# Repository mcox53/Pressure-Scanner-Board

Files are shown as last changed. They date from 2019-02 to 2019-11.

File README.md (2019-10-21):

# Pressure-Scanner-Board

Fab To-Do List:
- ~~Add I2C pull up resistors~~
- ~~Revise SPI pin pads to reflect correct configuration~~
- ~~Edit MCU pins once variant files finalized~~
- ~~Complete board BOM~~
- ~~Create changelog~~
- ~~Create PCB footprints and export netlist~~
- ~~Board layout~~
- ~~Design case~~
- ~~Design review~~
- ~~Finalize and release~~
- ~~Order board + parts~~
- ~~Assemble board~~

Test To-Do List:
- ~~Confirm communication with CAN Controller IC~~
- ~~Incorporate basic changes to variant files to support SPI~~
- ~~Test sending and receiving of CAN messages~~
- ~~Confirm communication with Static Pressure Sensor~~
- ~~Confirm communication with Differential Pressure Sensors~~
- ~~Test code to confirm operation of Differential Pressure Sensors.~~
- Test differential pressure sensors with manometer to verify full range of operation. (CC: Charlie Kniffin)
- Weak solder points of SS_0 and SS_3. Fix at shop with reflow station.
- Draft of application code (reading sensors -> preparing data frames -> sending over CAN)
- Prepare Interface Control Document (ICD) and add to AIM CAN configuration
- Finalize application code

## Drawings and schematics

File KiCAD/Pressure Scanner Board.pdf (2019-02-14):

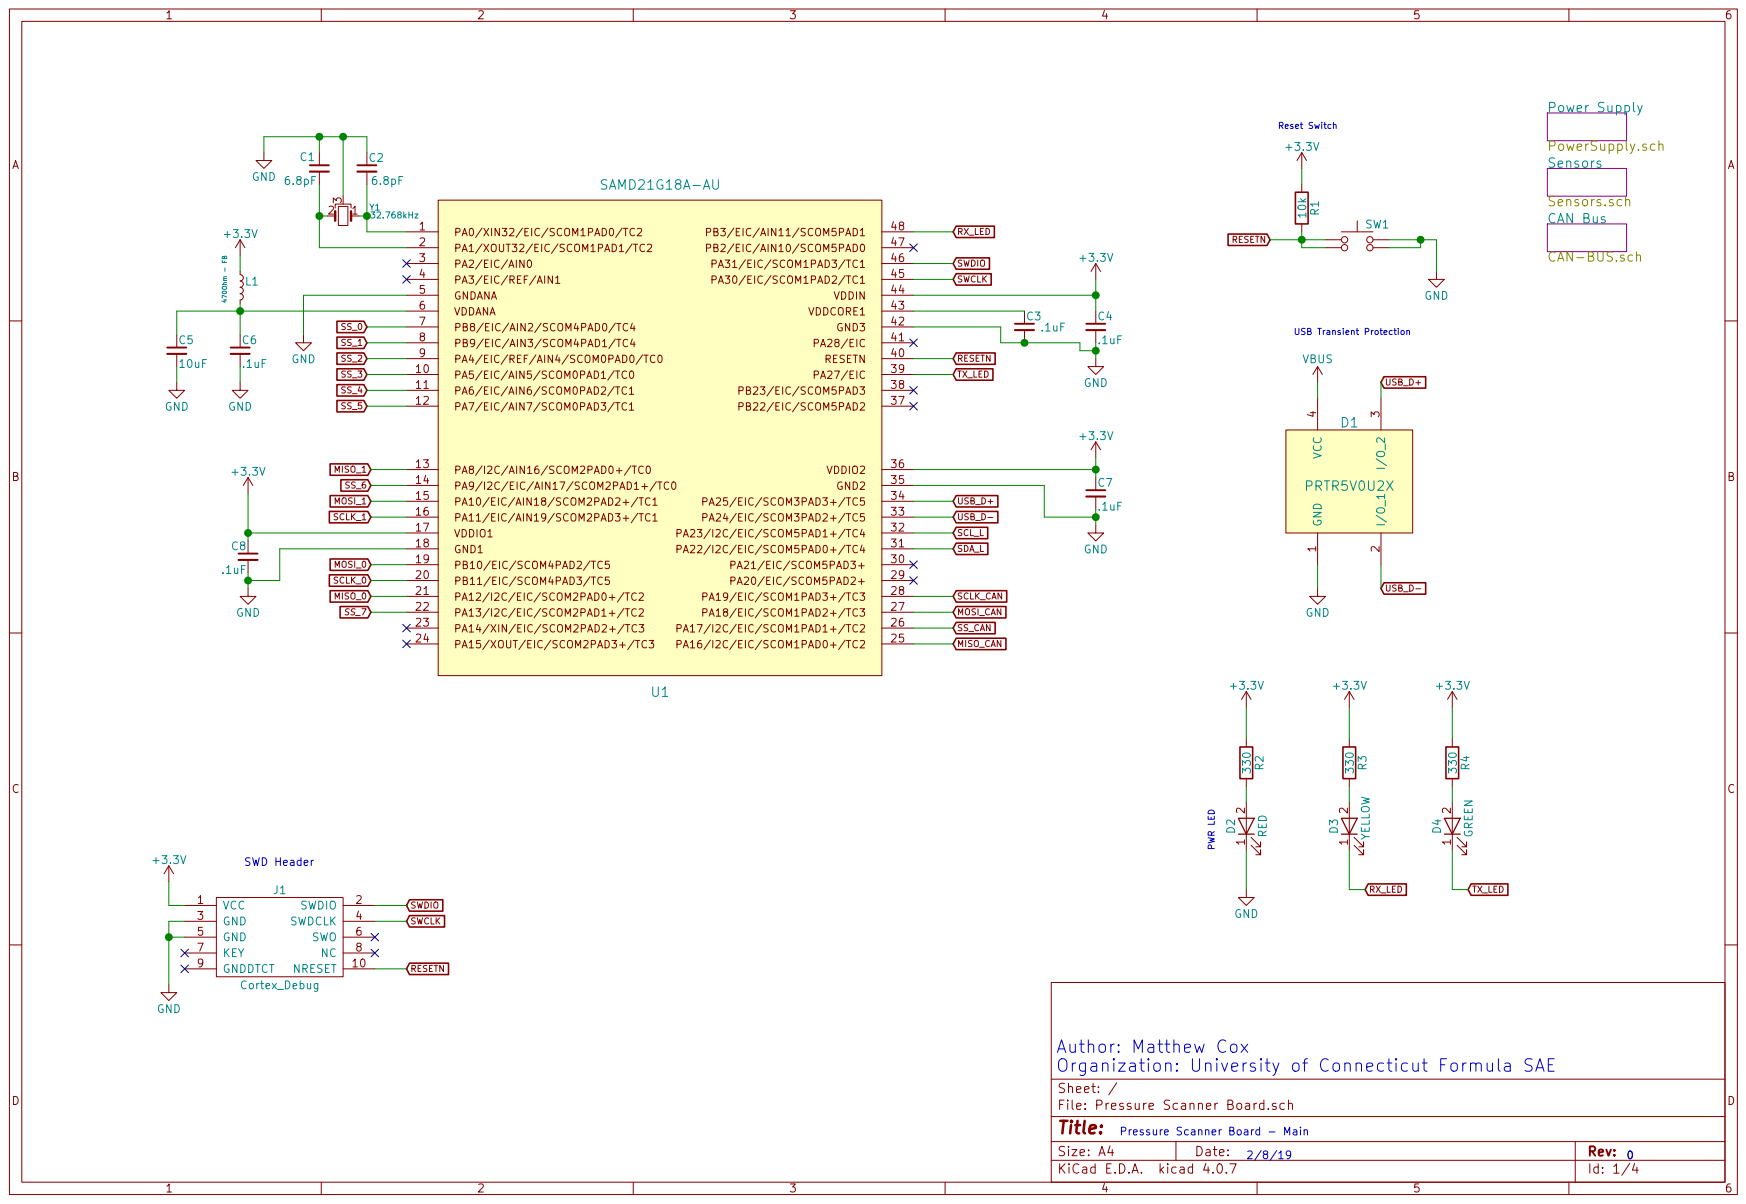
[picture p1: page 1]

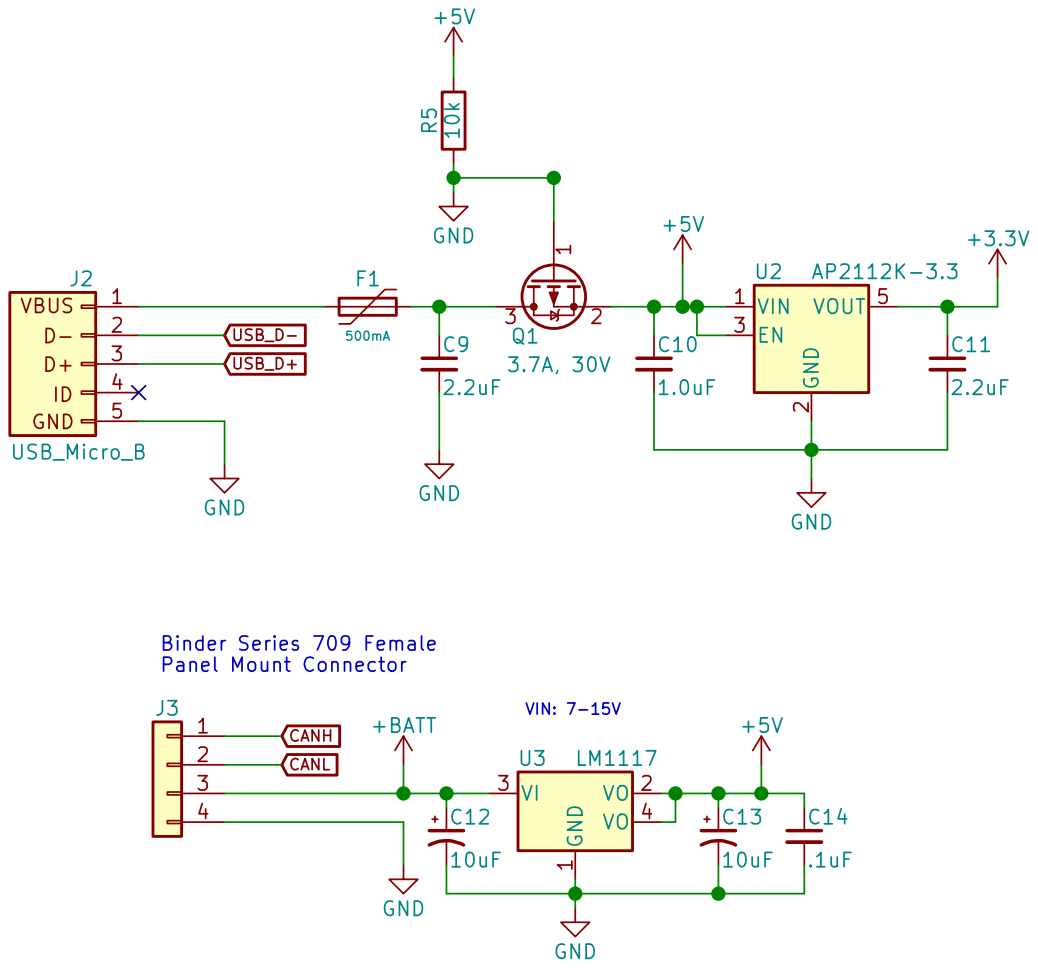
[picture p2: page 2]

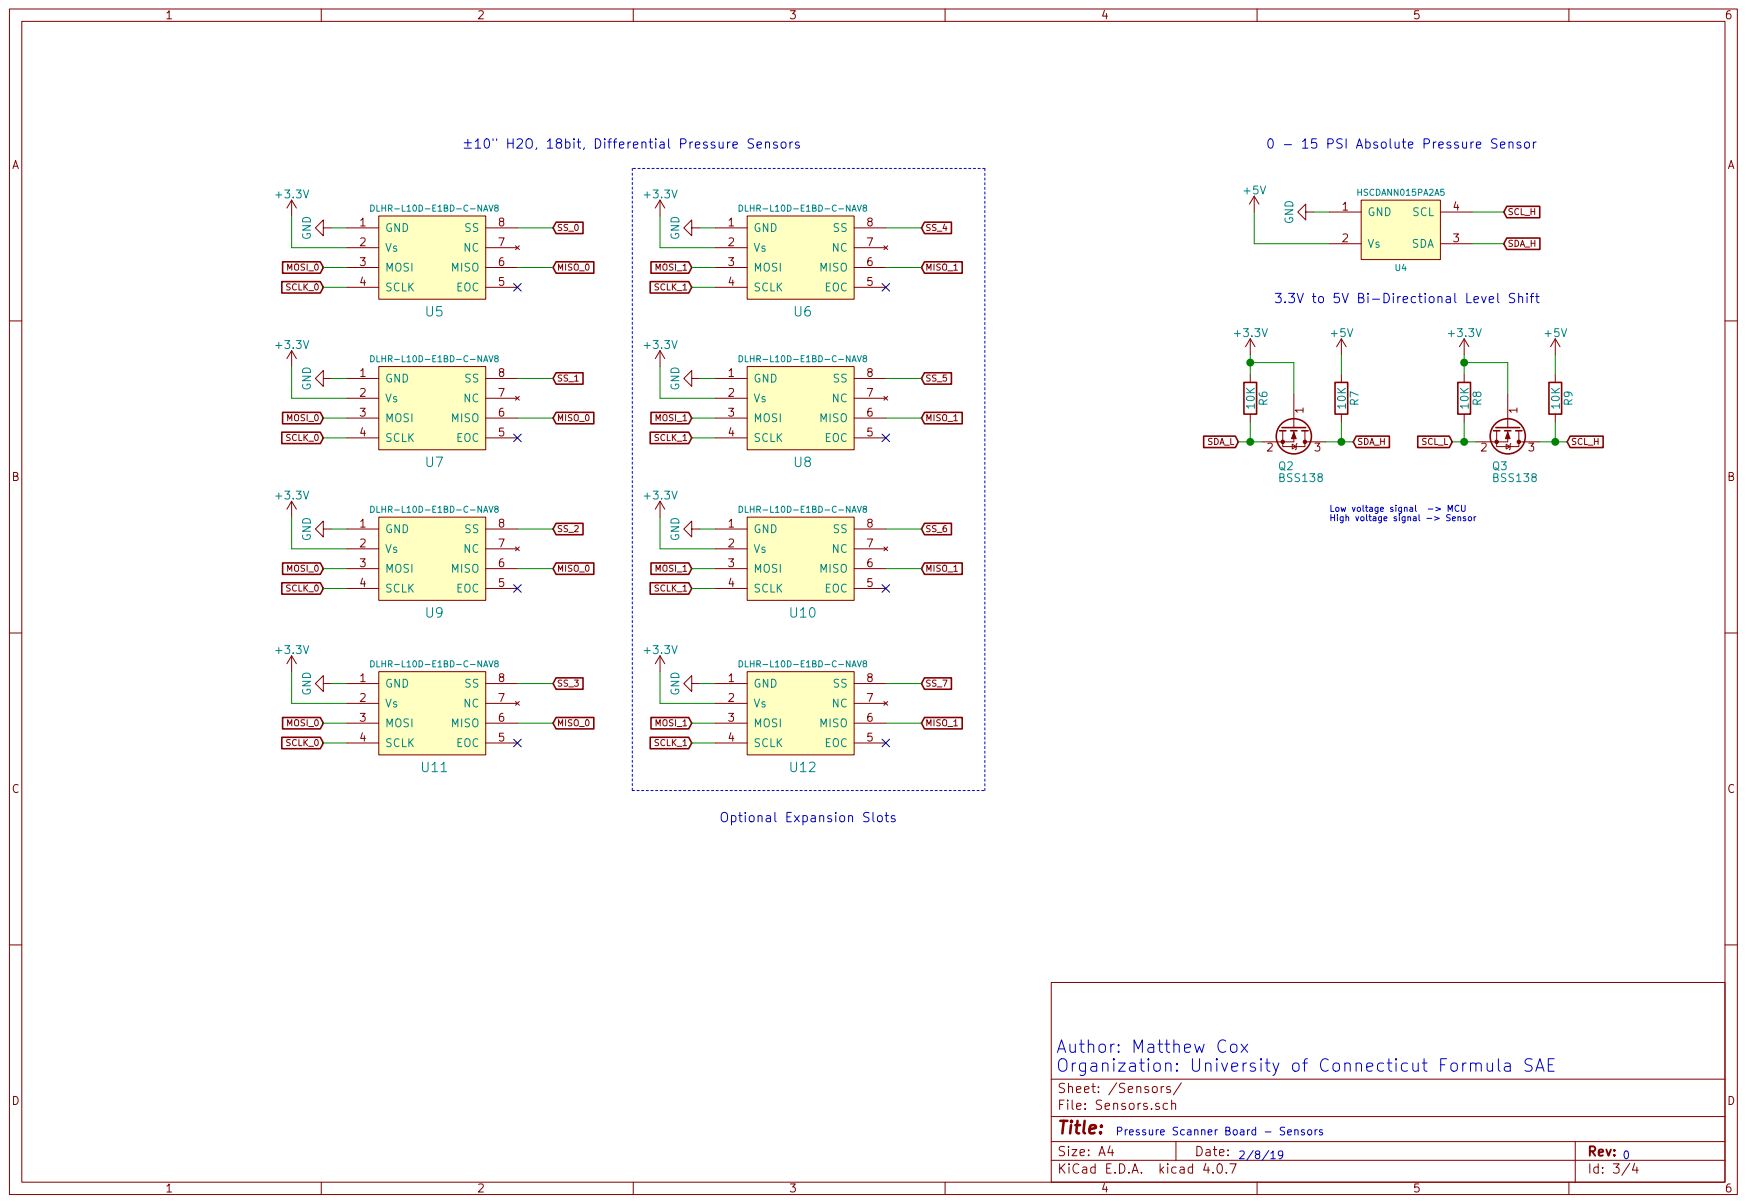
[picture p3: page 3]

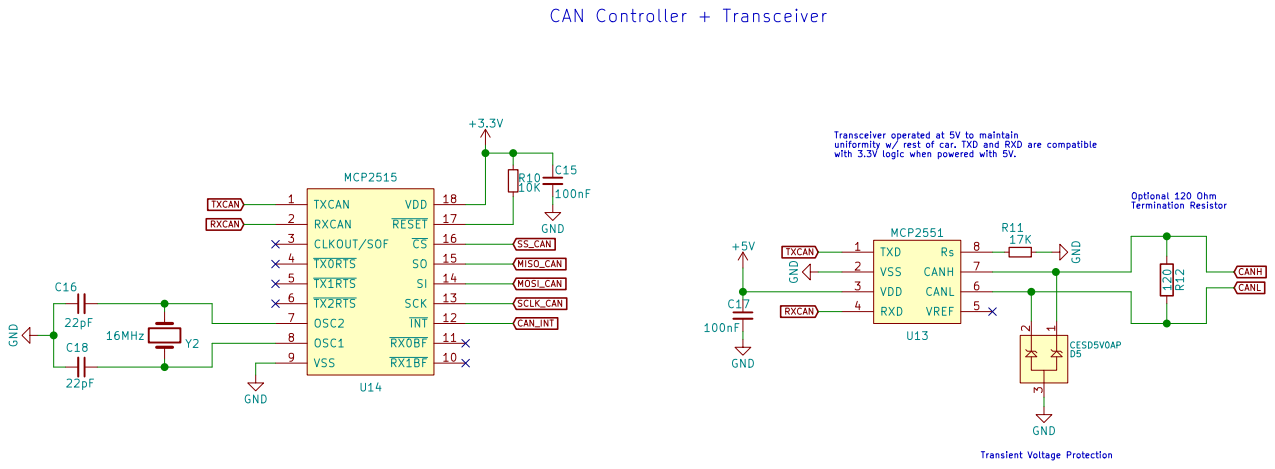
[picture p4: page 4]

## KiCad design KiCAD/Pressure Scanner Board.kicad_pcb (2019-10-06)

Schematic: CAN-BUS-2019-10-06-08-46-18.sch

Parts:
C15, C17: 0.1uF; C_0603
C16, C18: 22pF; C_0603
D3: ESDA6V1L; SOT-23
R10: 10K; R_0603
R11: 16.9K; R_0603
R12: 120; R_0603
U13: MCP2551; SOIC-8_3.9x4.9mm_Pitch1.27mm
U14: MCP2515; SOIC-18W_7.5x11.6mm_Pitch1.27mm
Y2: 16MHz; 9B-16.000MEEJ-B

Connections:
+3V3: C15.1, R10.1, U14.18; also elsewhere on the board
+5V: C17.1, U13.3; also elsewhere on the board
/CAN Bus/OSC+: C16.2, U14.7, Y2.1
/CAN Bus/OSC-: C18.1, U14.8, Y2.2
CAN+: D3.1, R12.1, U13.7; also elsewhere on the board
CAN-: D3.2, R12.2, U13.6; also elsewhere on the board
GND: C15.2, C16.1, C17.2, C18.2, D3.3, R11.2, U13.2, U14.9; also elsewhere on the board
MISO_CAN: U14.15; also elsewhere on the board
MOSI_CAN: U14.14; also elsewhere on the board
unnamed: R10.2, U14.17
unnamed: R11.1, U13.8
RXCAN: U13.4, U14.2
SCLK_CAN: U14.13; also elsewhere on the board
SS_CAN: U14.16; also elsewhere on the board
TXCAN: U13.1, U14.1

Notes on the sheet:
Author: Matthew Cox Organization: University of Connecticut Formula SAE
Pressure Scanner Board - CAN Bus Interface
2/8/19
CAN Controller + Transceiver
Optional 120 Ohm Termination Resistor
Transient Voltage Protection
Named this way so pcbnew acknowledges differential pair

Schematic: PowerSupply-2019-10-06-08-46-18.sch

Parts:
C9, C11: 2.2uF; C_0603
C10: 1.0uF; C_0603
C12, C13: 10uF; C_1206
C14: .1uF; C_0603
F1: 500mA; R_1210
J2: USB_Micro_B; 10104110-0001LF
J3: Conn_01x04; JST_PH_B4B-PH-K_04x2.00mm_Straight
Q1: 3.7A, 30V; SOT-23
R5: 10k; R_0603
U2: AP2112K-3.3; SOT-23-5
U3: LM1117; SOT-223-3_TabPin2

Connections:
+3V3: C11.1, U2.5; also elsewhere on the board
+5V: C10.1, C13.1, C14.1, Q1.2, R5.2, U2.1, U2.3, U3.2; also elsewhere on the board
+BATT: C12.1, J3.1, U3.3
CAN+: J3.3; also elsewhere on the board
CAN-: J3.4; also elsewhere on the board
GND: C9.2, C10.2, C11.2, C12.2, C13.2, C14.2, J2.5, J3.2, Q1.1, R5.1, U2.2, U3.1; also elsewhere on the board
unnamed: C9.1, F1.1, Q1.3
USB_D+: J2.3; also elsewhere on the board
USB_D-: J2.2; also elsewhere on the board
VBUS: F1.2, J2.1; also elsewhere on the board

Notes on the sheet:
VIN: 7-15V
Author: Matthew Cox Organization: University of Connecticut Formula SAE
Pressure Scanner Board - Power Supply
2/8/19
Flying leads terminate to 0.1" pin headers

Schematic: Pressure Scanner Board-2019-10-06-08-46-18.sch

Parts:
C1, C2: 6.8pF; C_0603
C3, C4, C6, C7, C8: 0.1uF; C_0603
C5: 10uF; C_1206
D1: PRTR5V0U2X; SOT-143
D2: RED; LED_1206
J1: Cortex_Debug; Pin_Header_Straight_2x05_Pitch1.27mm
L1: 470Ohm - FB; L_0603
R1: 10k; R_0603
R2: 330; R_0603
SW1: FSMCTTR
U1: SAMD21G18A-AU; QFP50P900X900X120-48N
Y1: 32.768kHz; CMR200T

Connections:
+3V3: C4.1, C7.1, C8.1, J1.1, L1.1, R1.1, R2.1, U1.17, U1.36, U1.44; also elsewhere on the board
/OSC+: C2.2, U1.1, Y1.1
/OSC-: C1.2, U1.2, Y1.2
GND: C1.1, C2.1, C3.2, C4.2, C5.2, C6.2, C7.2, C8.2, D1.1, D2.1, J1.3, J1.5, SW1.3, SW1.4, U1.5, U1.18, U1.35, U1.42, Y1.3; also elsewhere on the board
MISO_0: U1.21; also elsewhere on the board
MISO_CAN: U1.25; also elsewhere on the board
MOSI_0: U1.19; also elsewhere on the board
MOSI_CAN: U1.27; also elsewhere on the board
unnamed: C3.1, U1.43
unnamed: C5.1, C6.1, L1.2, U1.6
unnamed: D2.2, R2.2
RESETN: J1.10, R1.2, SW1.1, SW1.2, U1.40
SCLK_0: U1.20; also elsewhere on the board
SCLK_CAN: U1.28; also elsewhere on the board
SCL_L: U1.32; also elsewhere on the board
SDA_L: U1.31; also elsewhere on the board
SS_0: U1.13; also elsewhere on the board
SS_1: U1.14; also elsewhere on the board
SS_2: U1.15; also elsewhere on the board
SS_3: U1.16; also elsewhere on the board
SS_CAN: U1.26; also elsewhere on the board
SWCLK: J1.4, U1.45
SWDIO: J1.2, U1.46
USB_D+: D1.3, U1.34; also elsewhere on the board
USB_D-: D1.2, U1.33; also elsewhere on the board
VBUS: D1.4; also elsewhere on the board

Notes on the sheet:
SWD Header
PWR LED
Reset Switch
USB Transient Protection
Pressure Scanner Board - Main
2/8/19
Author: Matthew Cox Organization: University of Connecticut Formula SAE

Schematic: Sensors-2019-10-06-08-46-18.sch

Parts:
Q2, Q3: BSS138; SOT-23
R6, R7, R8, R9: 10K; R_0603
U4: HSCDANN015PA2A5
U5, U7, U9, U11: DLHR-L10D-E1BD-C-NAV8

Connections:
+3V3: Q2.1, Q3.1, R6.1, R8.1, U5.2, U7.2, U9.2, U11.2; also elsewhere on the board
+5V: R7.1, R9.1, U4.2; also elsewhere on the board
GND: U4.1, U5.1, U7.1, U9.1, U11.1; also elsewhere on the board
MISO_0: U5.6, U7.6, U9.6, U11.6; also elsewhere on the board
MOSI_0: U5.3, U7.3, U9.3, U11.3; also elsewhere on the board
unnamed: U4.5, U4.6
unnamed: U4.7, U4.8
SCLK_0: U5.4, U7.4, U9.4, U11.4; also elsewhere on the board
SCL_H: Q3.3, R9.2, U4.4
SCL_L: Q3.2, R8.2; also elsewhere on the board
SDA_H: Q2.3, R7.2, U4.3
SDA_L: Q2.2, R6.2; also elsewhere on the board
SS_0: U5.8; also elsewhere on the board
SS_1: U7.8; also elsewhere on the board
SS_2: U9.8; also elsewhere on the board
SS_3: U11.8; also elsewhere on the board

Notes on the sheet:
±10" H2O, 18bit, Differential Pressure Sensors
0 - 15 PSIA Pressure Sensor
3.3V to 5V Bi-Directional Level Shift
Pressure Scanner Board - Sensors
2/8/19
Author: Matthew Cox Organization: University of Connecticut Formula SAE
Low voltage signal -> MCU High voltage signal -> Sensor

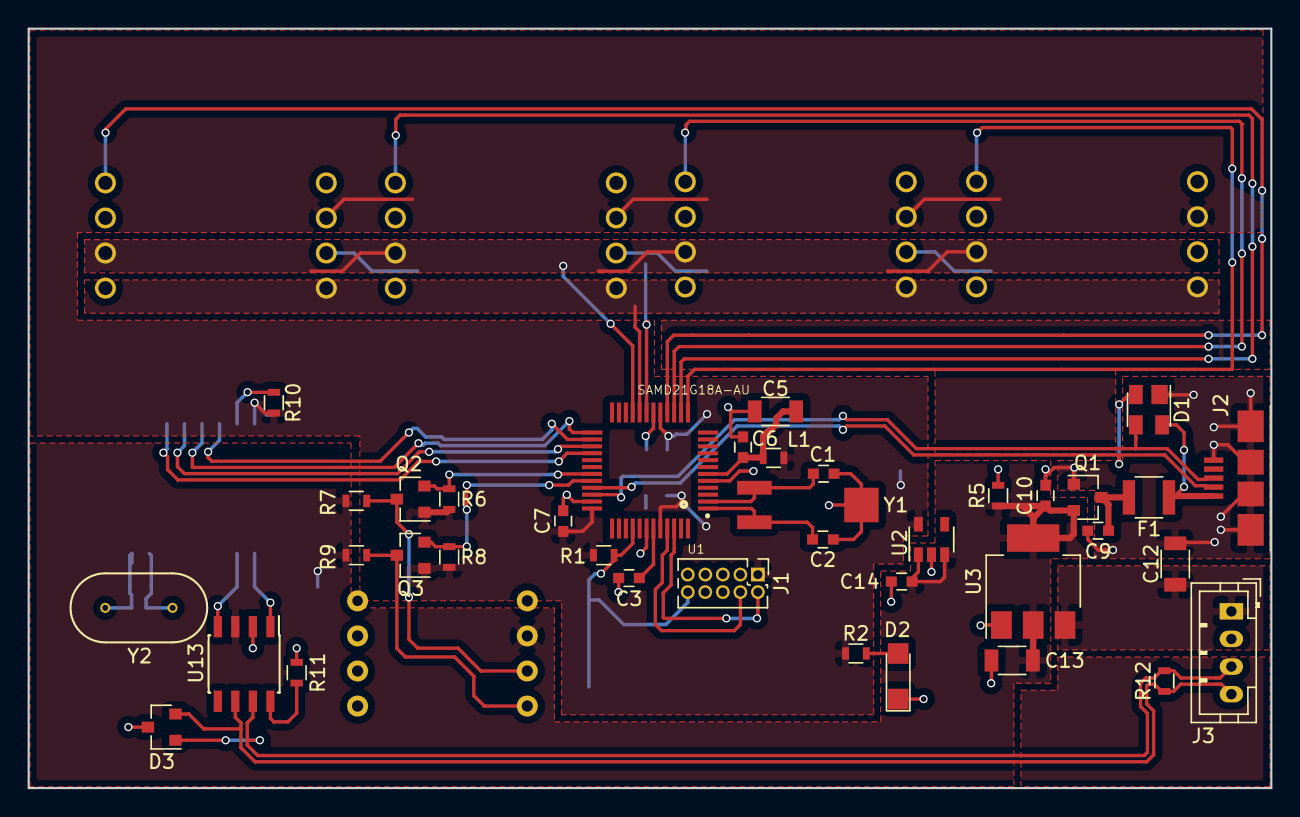
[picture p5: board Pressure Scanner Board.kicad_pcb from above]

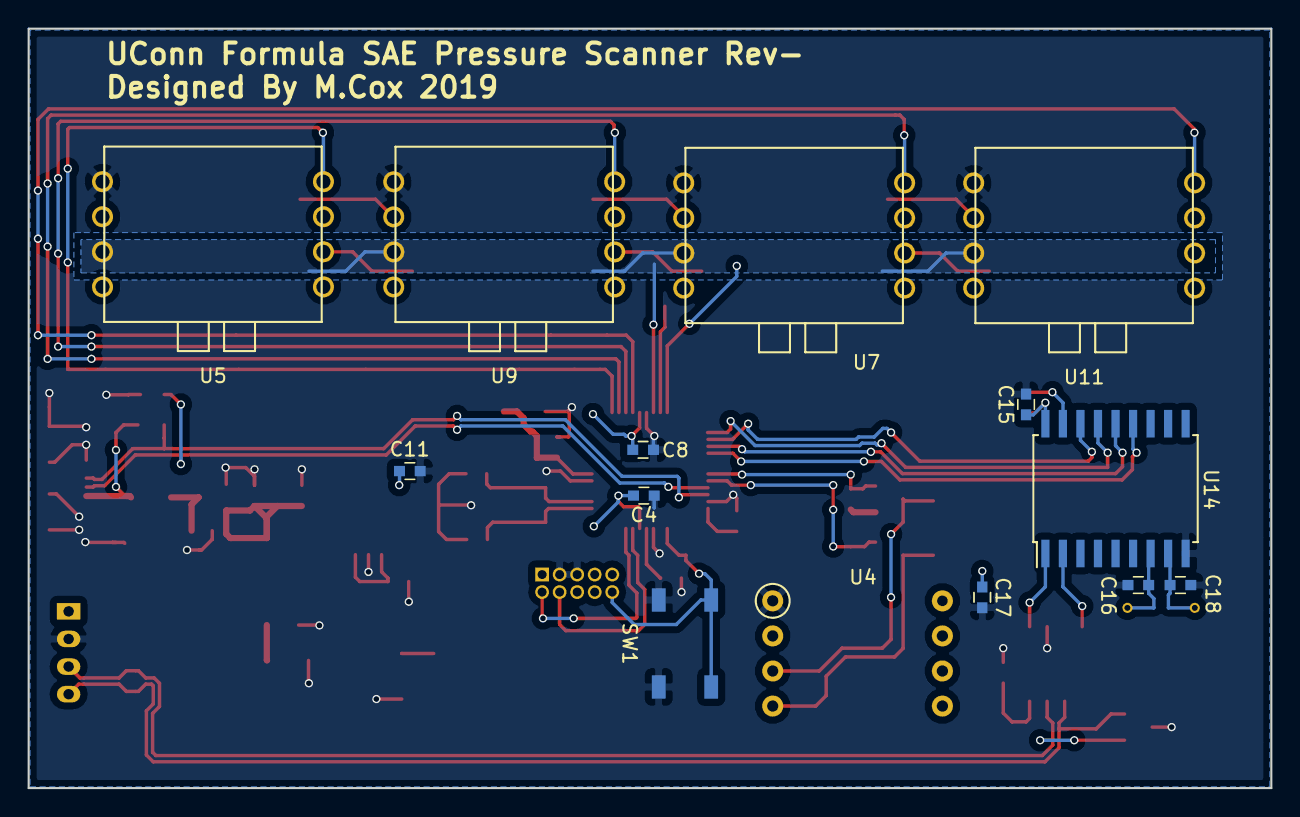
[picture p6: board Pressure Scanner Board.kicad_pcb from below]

Board: 2 copper layers, 90.0 x 55.0 mm, 52 parts (14 on the bottom side), 41 nets.

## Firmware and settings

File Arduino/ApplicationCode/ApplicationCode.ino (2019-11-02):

/*
 * Author: M. Cox
 * Date: 1/3/19
 * Updated: 10/20/19
 * Description: Testing operation of DLHR-L10D-E1BD-C-NAV8
 * differential pressure sensor on production board
 * Status: Working!
 */
#include <SPI.h>
#include "wiring_private.h"
#include "mcp_can.h"

// Sensor Constants
#define startSingleRead 0xAA
#define startAvg2       0xAC
#define startAvg4       0xAD
#define startAvg8       0xAE
#define startAvg16      0xAF

#define SensorReadByte  0xF0      // This must be followed by 6 bytes of 0x00, done in function
#define SensorStatus    0xF0      // Send only this one byte for status

#define CAN_SS 13

/* 
 *  Define a new SPI module on SERCOM4
 *  Digital Pin 23 / PB10 / SERCOM4, PAD2 -> MOSI
 *  Digital Pin 24 / PB11 / SERCOM4, PAD3 -> SCK
 *  Digital Pin 22 / PA12 / SERCOM4, PAD0 -> MISO
 *  SPI_PAD_2_SCK_3 indicates MOSI is on PAD2 and SCK on PAD3
 *  SERCOM_RX_PAD_2 indicates MISO is on PAD 2
 *  These pins are already set to PIO_SERCOM_ALT by default for this board
 *  No pinPeripheral() function calls are necessary
 */

SPIClass PressureSPI(&sercom4, 22, 24, 23, SPI_PAD_2_SCK_3, SERCOM_RX_PAD_0);

SPISettings Standard(1000000, MSBFIRST, SPI_MODE0);

const int SS_0 = 4;
const int SS_1 = 3;
const int SS_2 = 1;
const int SS_3 = 0;

uint32_t sensor1;
uint32_t sensor2;
uint32_t sensor3;
uint32_t sensor4;

byte canArray[8] = {0, 0, 0, 0, 0, 0, 0, 0};

MCP_CAN CAN(CAN_SS);

void setup() {
  SerialUSB.begin(115200);
  while(!SerialUSB);

   // initalize the chip select pins:
  pinMode(SS_0, OUTPUT);
  pinMode(SS_1, OUTPUT);
  pinMode(SS_2, OUTPUT);
  pinMode(SS_3, OUTPUT);
  
  // start the SPI library:
  PressureSPI.begin();

  pinPeripheral(22, PIO_SERCOM_ALT);
  pinPeripheral(23, PIO_SERCOM_ALT);
  pinPeripheral(24, PIO_SERCOM_ALT);
  pinPeripheral(0, PIO_DIGITAL);
  pinPeripheral(1, PIO_DIGITAL);

  digitalWrite(SS_0, HIGH);
  digitalWrite(SS_1, HIGH);
  digitalWrite(SS_2, HIGH);
  digitalWrite(SS_3, HIGH);

  while (CAN_OK != CAN.begin(CAN_1000KBPS)){
    SerialUSB.println("CAN Bus init failed");
  }
  
}

void loop() {
  
  delay(200);
  sendData();
}

void sendData(void){

  // Issue measure commands to all sensors since they take 50ms to read
  sendMeasurecmd(startAvg16, SS_0);
  sendMeasurecmd(startAvg16, SS_1);
  sendMeasurecmd(startAvg16, SS_2);
  
  sensor1 = readSensor(SS_0);
  sensor2 = readSensor(SS_1);
  sensor3 = readSensor(SS_2);

  SerialUSB.println("Sensor Read Success");

  canArray[0] = sensor1 >> 8;
  canArray[1] = sensor1;
  canArray[2] = sensor2 >> 8;
  canArray[3] = sensor2;
  canArray[4] = sensor3 >> 8;
  canArray[5] = sensor3;

  CAN.sendMsgBuf(0x5D, 0, 8, canArray);

  SerialUSB.println("CAN Send Data Success");
}

uint32_t readSensor(const int chipSelectPin) {

  uint32_t sensorReading;
  byte chipStatus = 0;
  bool measurementStatus = 0;
  
  while(measurementStatus == 0){
    chipStatus = readStatus(chipSelectPin);
    byte chipTest = (chipStatus >> 5) & 0b001;
    if(chipTest == 0){
      measurementStatus = 1; 
    }
    delay(5);
  }

  sensorReading = readMeasurement(chipSelectPin);
  measurementStatus = 0;

  return sensorReading;
}

void sendMeasurecmd(byte command, const int chipSelectPin) {

  // Initiate a SPI Transaction
  PressureSPI.beginTransaction(Standard);
  
  // Lower SS pin
  digitalWrite(chipSelectPin, LOW);

  // Measurement commands are a single byte followed by 2 dummy bytes
  PressureSPI.transfer(command); 
  PressureSPI.transfer(0x00);
  PressureSPI.transfer(0x00);

  // Raise SS pin
  digitalWrite(chipSelectPin, HIGH);

  // Complete SPI Transaction
  PressureSPI.endTransaction();
}

uint32_t readMeasurement(const int chipSelectPin){

  uint8_t readByte = 0;
  uint32_t pressure = 0;

  // Initiate a SPI Transaction
  PressureSPI.beginTransaction(Standard);
  
  // Lower SS pin
  digitalWrite(chipSelectPin, LOW);
  
  // Read in status byte
  readByte = PressureSPI.transfer(SensorReadByte);

  // Read in pressure data bytes
  for(uint8_t i = 3; i > 0; i--){
    readByte = PressureSPI.transfer(0x00);
    pressure |= (readByte << (8 * (i - 1)));
  }

  // Send the other three dummy bytes but don't read back the temperature
  PressureSPI.transfer(0x00);
  PressureSPI.transfer(0x00);
  PressureSPI.transfer(0x00);
  
  // Raise SS pin
  digitalWrite(chipSelectPin, HIGH);

  // Complete SPI Transaction
  PressureSPI.endTransaction();
  
  return pressure;
}

byte readStatus(const int chipSelectPin){
  
  // Initiate a SPI Transaction
  PressureSPI.beginTransaction(Standard);

  // Lower SS pin
  digitalWrite(chipSelectPin, LOW);

  // Send dummy byte to read received byte
  byte statusByte = PressureSPI.transfer(SensorStatus);
  
  // Raise SS pin
  digitalWrite(chipSelectPin, HIGH);

  // Complete SPI Transaction
  PressureSPI.endTransaction();

  return statusByte;
}

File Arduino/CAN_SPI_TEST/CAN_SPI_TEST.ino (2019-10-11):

/*
 * Title: CAN SPI Test
 * Author: M. Cox
 * Date: 10/05/19
 * Description: Using Pressure Scanner Board to test
 * out the use of the CAN Bus and confirm operation.
 * CAN on this board is on a secondary SERCOM peripheral
 * but is mapped in the variants.h file to be the built in SPIClass object
 */

#include <SPI.h>
#include "wiring_private.h"
#include <mcp_can.h>

// Override default SPI settings
SPISettings Standard(2000000, MSBFIRST, SPI_MODE0);

// Define slave select pins
#define CAN_SS 13

MCP_CAN CAN(CAN_SS);

void setup() {

  SerialUSB.begin(115200);
  while(!SerialUSB);

  pinMode(CAN_SS, OUTPUT);
  digitalWrite(CAN_SS, HIGH);

  while (CAN_OK != CAN.begin(CAN_1000KBPS)){
    SerialUSB.println("CAN BUS Shield Init Failed");
  }
  
}

unsigned char test[8] = {0,0,0,0,0,0,0,0};

void loop() {

// Will add code to test transceiver

  test[7] += 1;
  
  if(test[7] == 100){
    test[7] = 0;
  }

  CAN.sendMsgBuf(0x00, 0, 8, test);
  SerialUSB.println("Sent Message\n");
  delay(1000);

}

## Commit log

2018-11-03 Sorting project files
    [Pressure Scanner Board.kicad_pcb, Pressure Scanner Board.sch]
2019-01-03 Static Pressure Sensor test code
2019-02-07 Sketch to test and verify working SPI commands for sensor
2019-02-07 Update sensor functions to use proper SPI sequence and settings
2019-02-08 Imported SAMD21 IP, made differential pressure sensor symbol
    [PowerSupply.sch, Sensors.sch]
2019-02-12 Fixed differential pressure sensor pinout
2019-02-12 Created static pressure sensor schematic symbol
2019-02-12 Pinned pressure sensors and added 3.3V - 5V level shifter
    [PowerSupply.sch, Pressure Scanner Board.sch]
2019-02-12 Import libraries to be reused from SAMD21-Dev-Board
2019-02-12 Place power supply from SAMD21-Dev-Board
    [PowerSupply.sch, Pressure Scanner Board.sch, Sensors.sch]
2019-02-13 Can Bus related Schematic Symbols (MCP2551, MCP2515, CESD5V0AP)
2019-02-13 Added CAN Bus Sheet
    [CAN-BUS.sch, PowerSupply.sch, Pressure Scanner Board.sch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]
2019-02-14 Generic USB Micro B Schematic Symbol
2019-02-14 Schematic Rev 0
    [CAN-BUS.sch, PowerSupply.sch, Pressure Scanner Board.sch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]
2019-02-20 Made pressure sensor footprints
2019-02-20 Associated sensor footprints with parts
    [CAN-BUS.sch, PowerSupply.sch, Pressure Scanner Board.sch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]
2019-03-12 Added footprints for all components and created BOM
    [CAN-BUS.sch, PowerSupply.sch, Pressure Scanner Board.sch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]
2019-03-17 Corrected schematic error, began layout.
    [CAN-BUS.sch, Sensors.sch]
2019-03-21 More layout
    [PowerSupply.sch, Pressure Scanner Board.kicad_pcb]
2019-03-23 Bit more layout, prepping to start routing soon
    [Pressure Scanner Board.kicad_pcb]
2019-03-27 Updated CAN Controller Crystal Footprint
2019-03-27 Began routing, added differential pair labels
    [CAN-BUS.sch, PowerSupply.sch, Pressure Scanner Board.kicad_pcb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]
2019-03-29 Redoing layout
    [CAN-BUS.sch, PowerSupply.sch, Pressure Scanner Board.kicad_pcb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]
2019-03-30 More Routing
    [CAN-BUS.sch, Pressure Scanner Board.kicad_pcb]
2019-04-16 More route
    [Pressure Scanner Board.kicad_pcb]
2019-04-24 Reset the routing
    [Pressure Scanner Board.kicad_pcb]
2019-07-12 Swapped most capacitors and resistors to 0603 footprint
    [Temp BOM.xlsx]
2019-07-12 Dropped 4 spare sensors, revising layout.
    [CAN-BUS.sch, PowerSupply.sch, Pressure Scanner Board.kicad_pcb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]
2019-07-12 Finished layout V0.01
    [CAN-BUS.sch, PowerSupply.sch, Pressure Scanner Board.kicad_pcb]
2019-07-12 Export Version 0.01 fab files
    [Pressure Scanner Board-B.Cu.gbl, Pressure Scanner Board-B.Mask.gbs, Pressure Scanner Board-B.SilkS.gbo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]
2019-07-19 Remove Temp BOM, return to mainline BOM in Drive
    [Temp BOM.xlsx]
2019-07-19 Tidy up soldermask, cleaned up copper pours. Waiting for final packaging design
    [Pressure Scanner Board-B.Cu.gbl, Pressure Scanner Board-B.Mask.gbs, Pressure Scanner Board-B.SilkS.gbo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]
2019-07-24 Change NPTH Mounting holes and swap to JST PH Series Connector
    [PowerSupply.sch, Pressure Scanner Board.kicad_pcb]
2019-07-24 Production 1 Fabrication Files
    [Pressure Scanner Board-B.Cu.gbl, Pressure Scanner Board-B.Mask.gbs, Pressure Scanner Board-B.SilkS.gbo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]
2019-07-26 Exported fab files in proper format for fab house
    [Pressure Scanner Board-B.Cu.gbl, Pressure Scanner Board-B.Mask.gbs, Pressure Scanner Board-B.SilkS.gbo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]
2019-10-06 Can bus confirmed operational on Rev- Production 1 Board
2019-10-06 Update remaining board tasks
2019-10-06 Update Project to KiCAD 5; Status: REV-, Production 1
    [CAN-BUS-2019-10-06-08-46-18.sch, PowerSupply-2019-10-06-08-46-18.sch, Pressure Scanner Board-2019-10-06-08-46-18.sch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]
2019-10-11 Testing production board for functionality
2019-10-20 Working and tested copy of code to read differential pressure sensors
2019-11-02 Draft of application code + test application for all 4 sensors
